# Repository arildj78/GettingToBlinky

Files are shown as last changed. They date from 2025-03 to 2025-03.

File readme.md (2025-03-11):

# Getting to Blinky
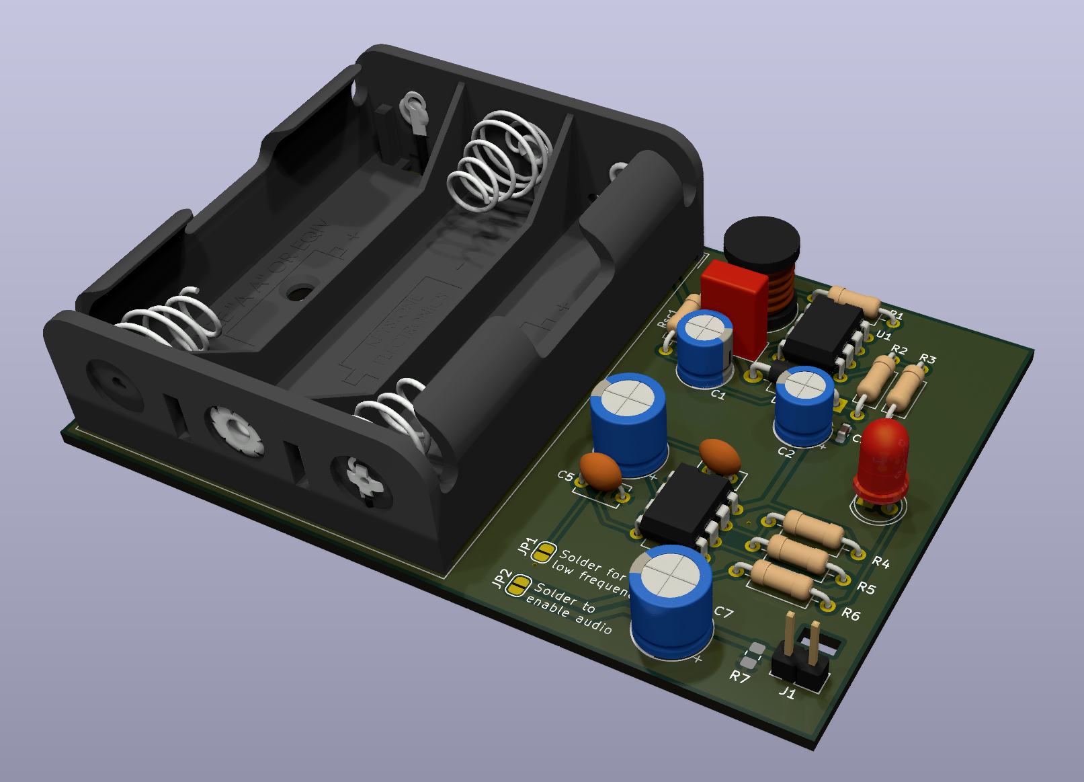
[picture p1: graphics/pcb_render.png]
Rendering of the pcb

This project is designed to introduce you to KiCad and electronics design. The gadget is battery powered and will blink a high luminosity LED as well as output a tone to a speaker. The frequency can be switched between 1 Hz and 440Hz with a solder jumper. The two integrated circuits are classics and are considered [jellybean](https://forum.digikey.com/t/what-are-jellybean-electronic-components/46180) parts.

## The schematic
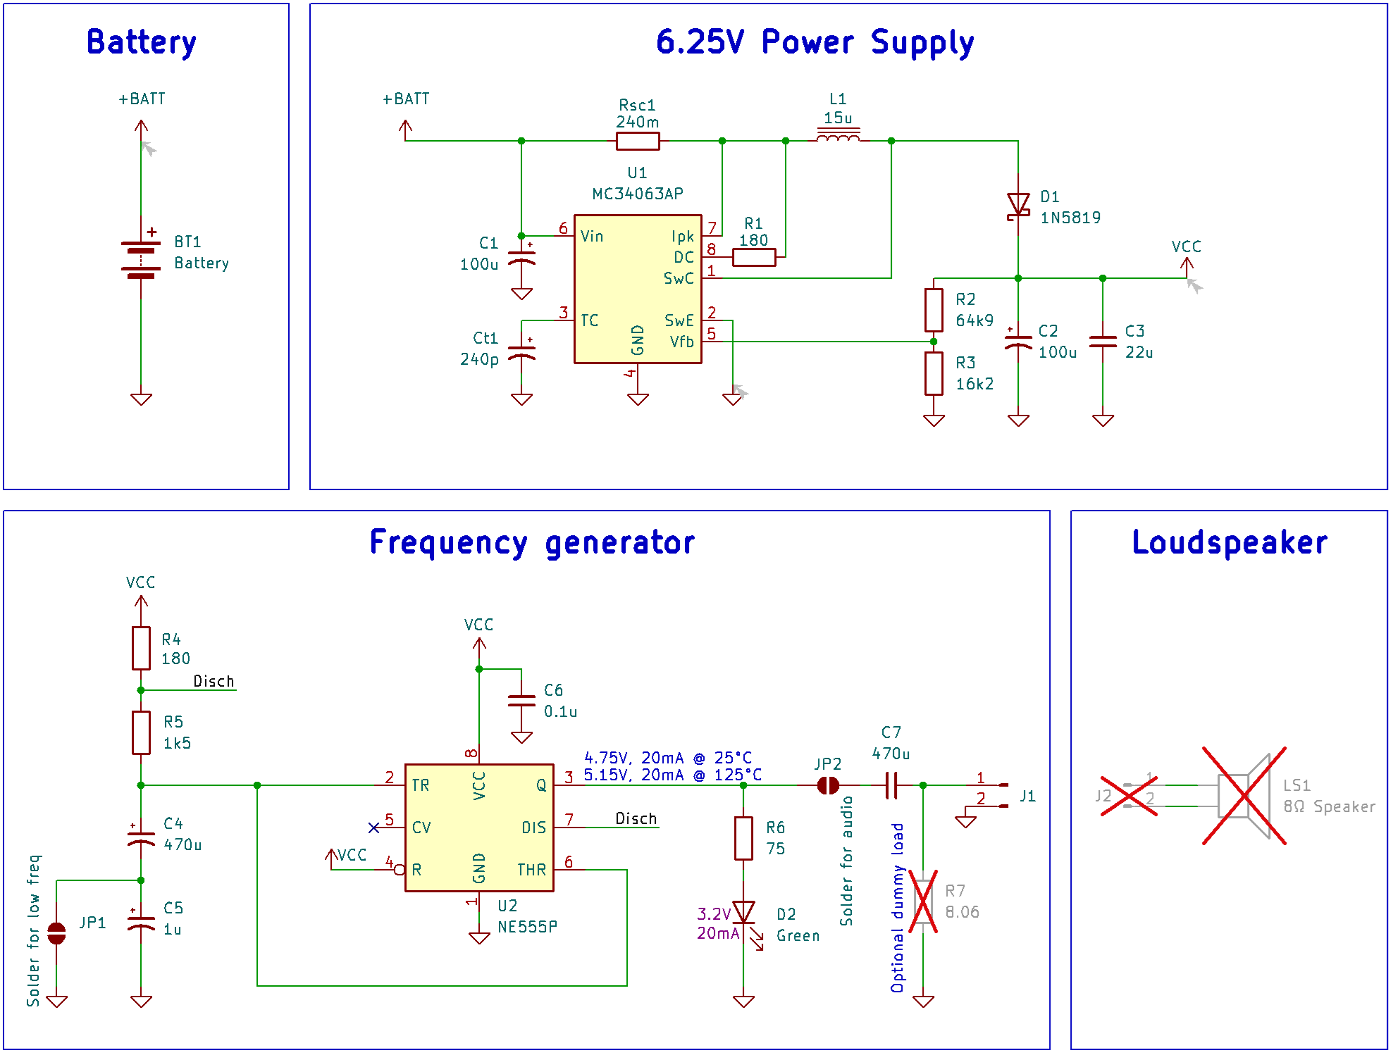
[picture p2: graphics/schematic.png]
Image of the schematic


## General design requirements
* Power supplied by [3 x AA batteries](https://www.digikey.no/en/products/detail/keystone-electronics/2464/303813)
* Generate the pulsed signal with a [555 timer](/datasheets/ne555.pdf) chip
* Boost the battery voltage with the [MC34063](/datasheets/MC34063A-D.pdf) DC-DC regulator
* Let the 555 timer drive 0.25 Watt into an 8Ω speaker without an additional amplifier
* Use only through hole parts in the design with two small exceptions
* Familiarize the designer with SMD parts of imperial size 0603 and 0805.
* Introduce some of the tools and techniques that are useful in KiCad
* Cut a slot in the PCB to use as strain relief for the speaker cable
* Use a two layer pcb design

## DC-DC regulator design decisions
* Input voltage 3.75V ±20%
    * An assumption is made that an alkaline cell with 50% of the energy left is at approximately 1.25V. We are using three of these in series.
* Output current 150mA
    * This is a compromise. Not all the way to 0.25 watt on the speaker and not maxing out the available current from the 555 timer chip. May change after prototyping.
* Output Voltage 6.25V
    * The voltage needs to be this high to get 2.4V voltage swing on the output when pulling 150mA from the output of the 555.
* Switching frequency 100kHz
    * A high switching frequency lets the inductor be small. This is the maximum frequency supported by the selected regulator.
* Output ripple voltage 100mV
    * An arbitrary value. Same as Dave chose in the YouTube video [EEVblog #110 - Let's Design a DC to DC Switch mode Converter](https://youtu.be/qGp82xhybs4).

## Teaching points in Schematic Editor
* Getting started with a new project i KiCad
* Placing parts and connecting them on the schematic
    * Place
    * Rotate
    * Mirror
    * Move
    * Grab
    * Wire
* Implementing the typical application found in the MC34063 and 555 datasheets
* Choosing component values from [E series of preferred numbers](https://en.wikipedia.org/wiki/E_series_of_preferred_numbers)
* Searching for parts on [DigiKey](https://digikey.com), [JLCPCB](https://jlcpcb.com/parts) and [LCSC](https://www.lcsc.com/)
* Choosing footprints
* Adding symbol data by using *fields* and the *Symbol Fields Table*
* Using the *Do not populate* and *Exclude from Bill Of Materials* (BOM) option
* The purpose of the 0.1µF decoupling capacitor
* Dividing a schematic into functional blocks
* Annotating the schematic
* Running Electrical Rules Check

## Teaching points in PCB Editor
* Switching from schematic to pcb
* Update PCB from schematic
* Move components into functional blocks
* Untangle the ratsnest
* Draw board outline
* Pre-define sizes for tracks and vias.
    * 0.3mm (0.012") track
    * 0.7mm (0.028") track
    * 1.0mm / 0.4mm via
* Route Tracks
    * Track size
    * Use of vias and multiple layers
* Create filled zones for ground (and power if the board had more layers)
* Use the 3D-viewer
* Use the Design Rules Check

## Suggested Parts list
|Reference |Value |Manufacturer |Part# |DigiKey# |Qty|
|---|---|---|---|---|---|
|BT1 |Battery  |Keystone Electronics |2464 |36-2464-ND |  1|
|C1,C2 |100u |Chinsan (Elite) |ED1E101MP26311U |4191-ED1E101MP26311UCT-ND  |  2|
|C3 |22u |Murata Electronics |GRM188C61E226ME01J|490-GRM188C61E226ME01JCT-ND|  1|
|C4,C7 |470u |Chinsan (Elite) |EK1C471MP30812 |4191-EK1C471MP30812CT-ND |  2|
|C5 |1u |TDK Corporation |FG24X7R1H105KRT06 |445-173374-1-ND |  1|
|C6 |0.1u |KEMET |C320C104M5R5TA |399-9776-ND |  1|
|Ct1 |240p |KEMET |C318C241K3G5TA |C318C241K3G5TA-ND |  1|
|D1 |1N5819 |STMicroelectronics |1N5819 |497-6610-1-ND |  1|
|D2 |Green |Inolux |INL-5AG30 |1830-1011-ND |  1|
|L1 |15u |Bourns Inc. |RLB0913-150K |RLB0913-150K-ND |  1|
|R1,R4 |180 |Stackpole Electronics Inc  |CF14JT180R |CF14JT180RCT-ND |  2|
|R2 |64k9 |YAGEO |MFR-25FRF52-64K9  |13-MFR-25FRF52-64K9CT-ND |  1|
|R3 |16k2 |YAGEO |MFR-25FTE52-16K2  |13-MFR-25FTE52-16K2CT-ND |  1|
|R5 |1k5 |YAGEO |MFR-25FTF52-1K5 |13-MFR-25FTF52-1K5CT-ND |  1|
|R6 |75 |Stackpole Electronics Inc  |CF14JT75R0 |CF14JT75R0CT-ND |  1|
|R7 |8.06 |KOA Speer Electronics, Inc.|RK73H2ATTD8R06F |2019-RK73H2ATTD8R06FCT-ND  |  1|
|Rsc1 |240m |YAGEO |MFR-25JR-52-0R24  |13-MFR-25JR-52-0R24CT-ND |  1|
|U1 |MC34063AP|onsemi |MC34063AP1G |MC34063AP1GOS-ND |  1|
|U2 |NE555P |Texas Instruments |NE555P |296-NE555P-ND |  1|

## Suggested Footprints
|Reference |Footprint |
|---|---|
|BT1 |Battery:BatteryHolder_TruPower_BH-331P_3xAA |
|C1,C2 |Capacitor_THT:CP_Radial_D6.3mm_P2.50mm |
|C3 |Capacitor_SMD:C_0603_1608Metric_Pad1.08x0.95mm_HandSolder |
|C4,C7 |Capacitor_THT:CP_Radial_D8.0mm_P3.50mm |
|C5 |Capacitor_THT:C_Disc_D5.1mm_W3.2mm_P5.00mm |
|C6 |Capacitor_THT:C_Disc_D5.0mm_W2.5mm_P2.50mm |
|Ct1 |Capacitor_THT:C_Rect_L7.0mm_W3.5mm_P5.00mm |
|D1 |Diode_THT:D_DO-41_SOD81_P10.16mm_Horizontal |
|D2 |LED_THT:LED_D5.0mm |
|L1 |Inductor_THT:L_Radial_D8.7mm_P5.00mm_Fastron_07HCP |
|R1,R2,R3,R4,R5,R6,Rsc1|Resistor_THT:R_Axial_DIN0207_L6.3mm_D2.5mm_P10.16mm_Horizontal|
|R7 |Resistor_SMD:R_0805_2012Metric_Pad1.20x1.40mm_HandSolder |
|U1,U2 |Package_DIP:DIP-8_W7.62mm |

## Reference material
* [EEVblog #110 - Let's Design a DC to DC Switch mode Converter](https://youtu.be/qGp82xhybs4)

## Useful tools
* [KiCad](https://www.kicad.org/)
* [LTspice circuit simulator](https://www.analog.com/en/resources/design-tools-and-calculators/ltspice-simulator.html)
* [Saturn PCB Design Toolkit](https://saturnpcb.com/saturn-pcb-toolkit/)
* [Resistor calculator](https://damien.douxchamps.net/elec/resdiv/)

## Useful web services
* [jlcpcb.com](https://jlcpcb.com/)
* [digikey.com](https://www.digikey.com)
* [lcsc.com](https://www.lcsc.com/)
* [Falstad circuit simulator](https://www.falstad.com/circuit/circuitjs.html)

## My favorite podcasts
* [The Amp Hour](https://theamphour.com/)
* [Embedded FM](https://embedded.fm/)
* [Hackaday](https://hackaday.com/tag/hackaday-podcast/)
* [The Unnamed Reverse Engineering Podcast](https://unnamedre.com/)

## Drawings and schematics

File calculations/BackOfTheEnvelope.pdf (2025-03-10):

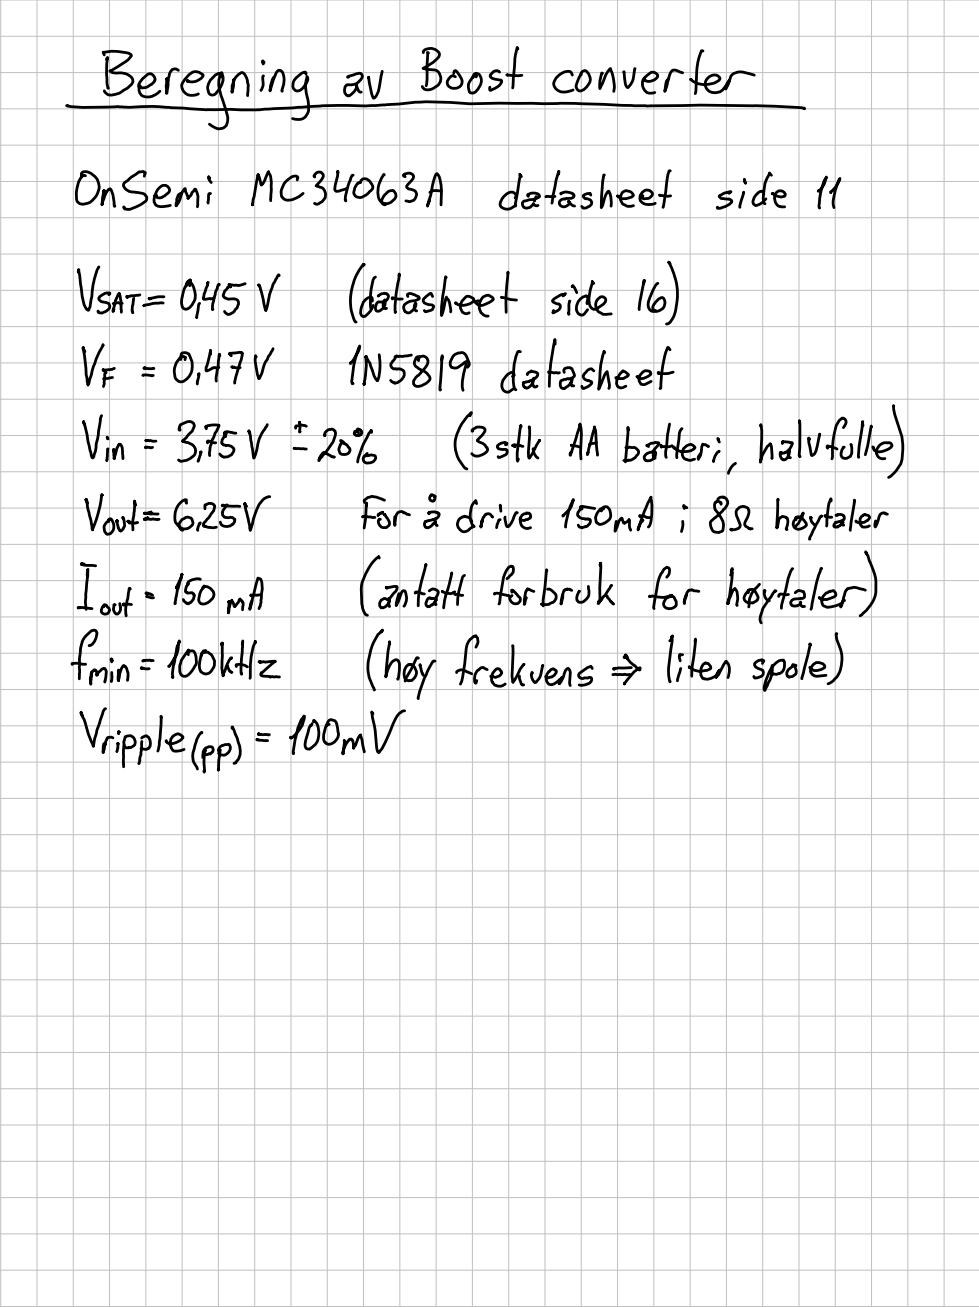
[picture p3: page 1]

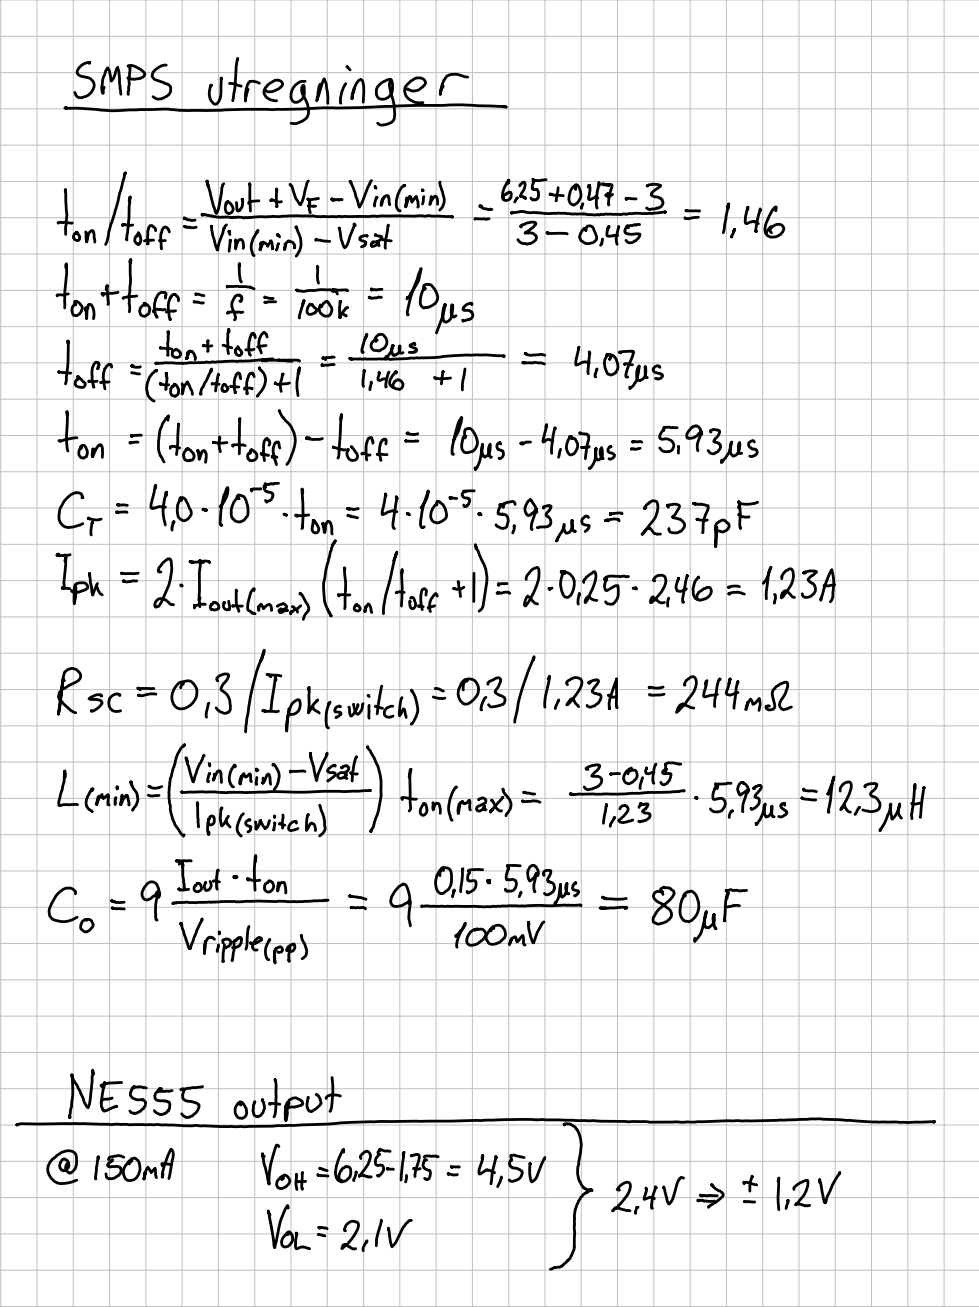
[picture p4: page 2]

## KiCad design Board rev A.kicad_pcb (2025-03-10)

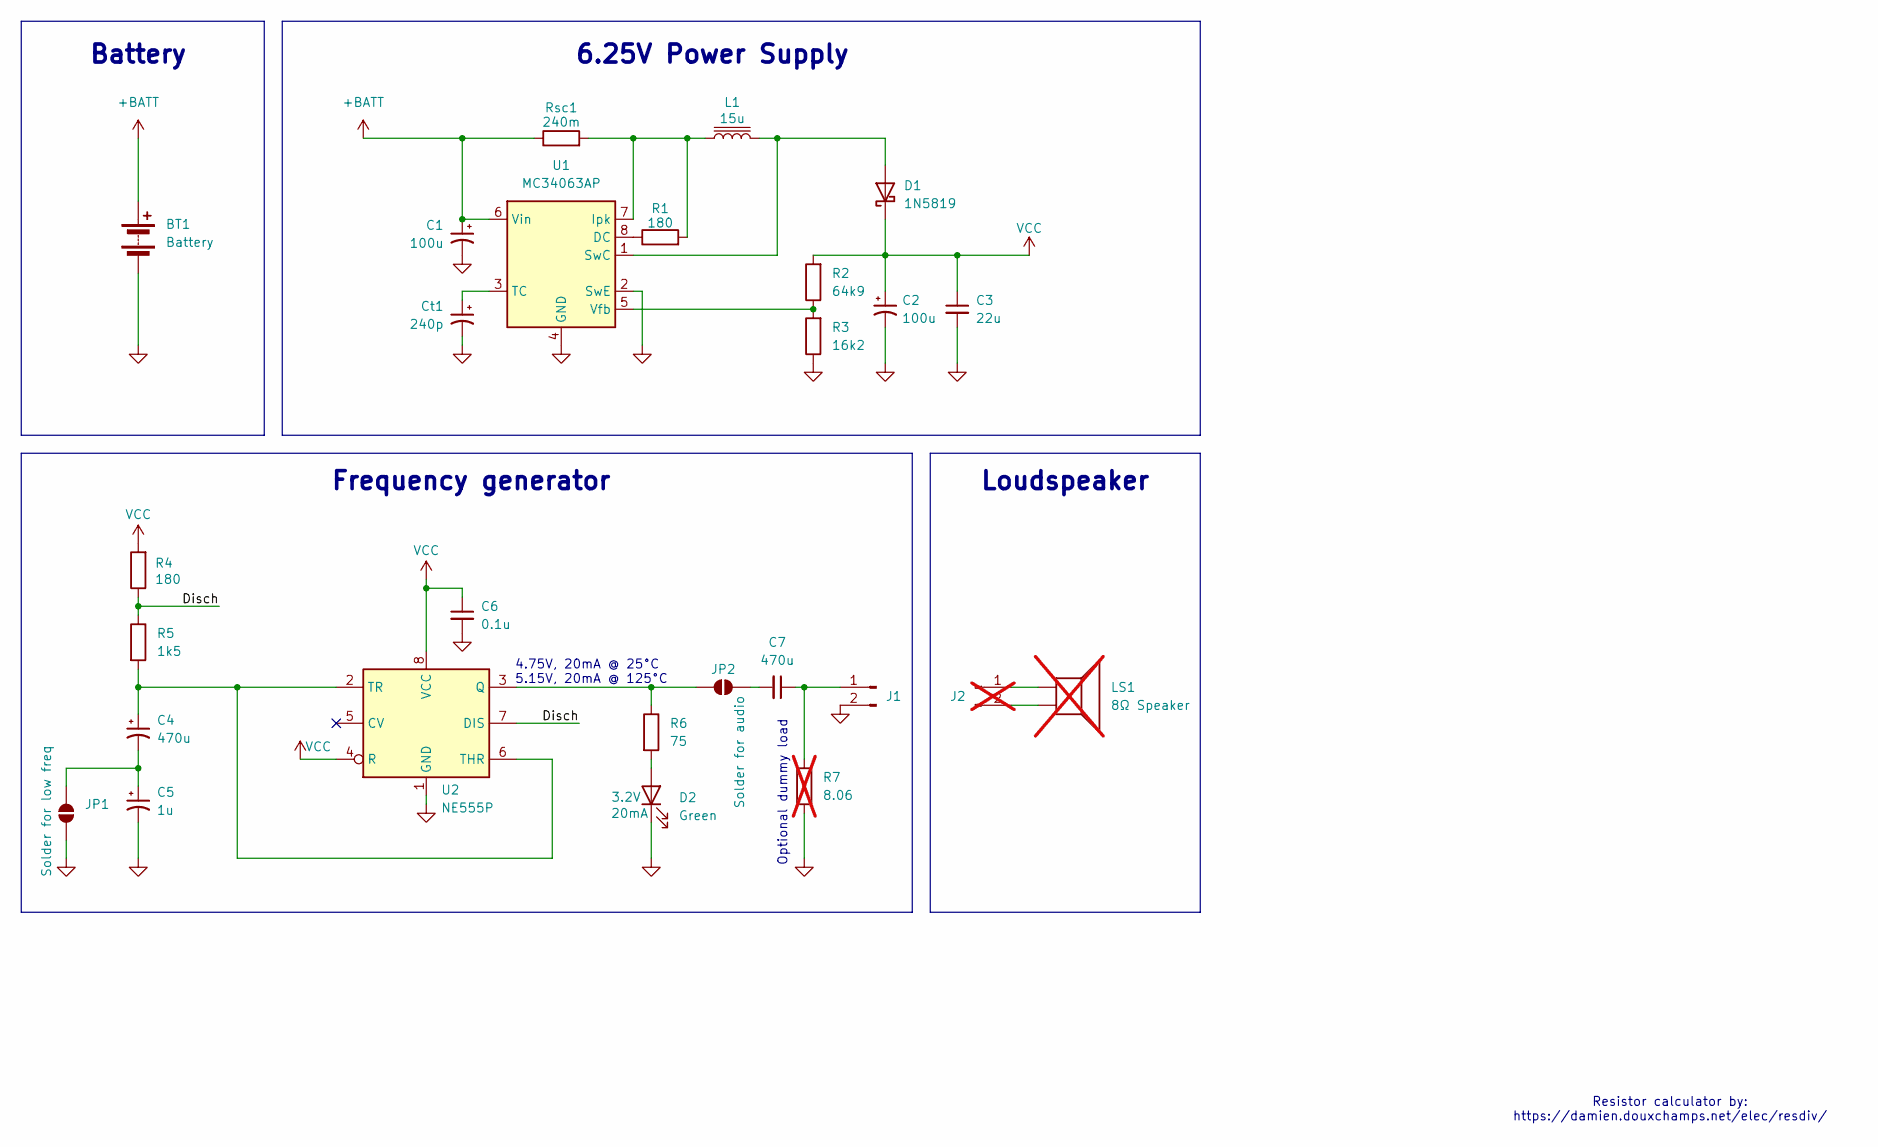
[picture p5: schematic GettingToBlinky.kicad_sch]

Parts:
BT1: Battery; BatteryHolder_TruPower_BH-331P_3xAA; Part# 2464; DigiKey# 36-2464-ND
C1, C2: 100u; CP_Radial_D6.3mm_P2.50mm; Part# ED1E101MP26311U; DigiKey# 4191-ED1E101MP26311UCT-ND
C3: 22u; C_0603_1608Metric_Pad1.08x0.95mm_HandSolder; Part# GRM188C61E226ME01J; DigiKey# 490-GRM188C61E226ME01JCT-ND
C4, C7: 470u; CP_Radial_D8.0mm_P3.50mm; Part# EK1C471MP30812; DigiKey# 4191-EK1C471MP30812CT-ND
C5: 1u; C_Disc_D5.1mm_W3.2mm_P5.00mm; Part# FG24X7R1H105KRT06; DigiKey# 445-173374-1-ND
C6: 0.1u; C_Disc_D5.0mm_W2.5mm_P2.50mm; Part# C320C104M5R5TA; DigiKey# 399-9776-ND
Ct1: 240p; C_Rect_L7.0mm_W3.5mm_P5.00mm; Part# C318C241K3G5TA; DigiKey# C318C241K3G5TA-ND
D1: 1N5819; D_DO-41_SOD81_P10.16mm_Horizontal; Part# 1N5819; DigiKey# 497-6610-1-ND
D2: Green; LED_D5.0mm; Part# INL-5AG30; DigiKey# 1830-1011-ND
J1: Conn_01x02_Pin; PinHeader_1x02_P2.54mm_Vertical
J2: Conn_01x02_Pin; PinHeader_1x02_P2.54mm_Vertical; not fitted
JP1: Solder for low freq; SolderJumper-2_P1.3mm_Open_RoundedPad1.0x1.5mm
JP2: Solder for audio; SolderJumper-2_P1.3mm_Open_RoundedPad1.0x1.5mm
L1: 15u; L_Radial_D8.7mm_P5.00mm_Fastron_07HCP; Part# RLB0913-150K; DigiKey# RLB0913-150K-ND
LS1: 8Ω Speaker; not fitted
R1, R4: 180; R_Axial_DIN0207_L6.3mm_D2.5mm_P10.16mm_Horizontal; Part# CF14JT180R; DigiKey# CF14JT180RCT-ND
R2: 64k9; R_Axial_DIN0207_L6.3mm_D2.5mm_P10.16mm_Horizontal; Part# MFR-25FRF52-64K9; DigiKey# 13-MFR-25FRF52-64K9CT-ND
R3: 16k2; R_Axial_DIN0207_L6.3mm_D2.5mm_P10.16mm_Horizontal; Part# MFR-25FTE52-16K2; DigiKey# 13-MFR-25FTE52-16K2CT-ND
R5: 1k5; R_Axial_DIN0207_L6.3mm_D2.5mm_P10.16mm_Horizontal; Part# MFR-25FTF52-1K5; DigiKey# 13-MFR-25FTF52-1K5CT-ND
R6: 75; R_Axial_DIN0207_L6.3mm_D2.5mm_P10.16mm_Horizontal; Part# CF14JT75R0; DigiKey# CF14JT75R0CT-ND
R7: 8.06; R_0805_2012Metric_Pad1.20x1.40mm_HandSolder; Part# RK73H2ATTD8R06F; DigiKey# 2019-RK73H2ATTD8R06FCT-ND; not fitted
Rsc1: 240m; R_Axial_DIN0207_L6.3mm_D2.5mm_P10.16mm_Horizontal; Part# MFR-25JR-52-0R24; DigiKey# 13-MFR-25JR-52-0R24CT-ND
U1: MC34063AP; DIP-8_W7.62mm; Part# MC34063AP1G; DigiKey# MC34063AP1GOS-ND
U2: NE555P; DIP-8_W7.62mm; Part# NE555P; DigiKey# 296-NE555P-ND

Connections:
+BATT: BT1.1 (+), C1.1, Rsc1.1, U1.6 (Vin)
/Disch: R4.1, R5.1, U2.7 (DIS)
GND: BT1.2 (-), C1.2, C2.2, C3.2, C5.2, C6.2, Ct1.2, D2.1 (K), J1.2, JP1.1 (A), R3.1, R7.2, U1.2 (SwE), U1.4 (GND), U2.1 (GND)
unnamed: D1.2 (A), L1.2, U1.1 (SwC)
unnamed: D2.2 (A), R6.2
unnamed: C7.1, J1.1, R7.1
unnamed: J2.1, LS1.1
unnamed: J2.2, LS1.2
unnamed: C4.2, C5.1, JP1.2 (B)
unnamed: C7.2, JP2.1 (A)
unnamed: JP2.2 (B), R6.1, U2.3 (Q)
unnamed: R1.1, U1.8 (DC)
unnamed: L1.1, R1.2, Rsc1.2, U1.7 (Ipk)
unnamed: Ct1.1, U1.3 (TC)
unnamed: R2.1, R3.2, U1.5 (Vfb)
unnamed: C4.1, R5.2, U2.2 (TR), U2.6 (THR)
VCC: C2.1, C3.1, C6.1, D1.1 (K), R2.2, R4.2, U2.4 (R), U2.8 (VCC)

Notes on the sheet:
4.75V, 20mA @ 25°C 5.15V, 20mA @ 125°C
Resistor calculator by: https://damien.douxchamps.net/elec/resdiv/
6.25V Power Supply
Optional dummy load
Loudspeaker
Battery
Frequency generator

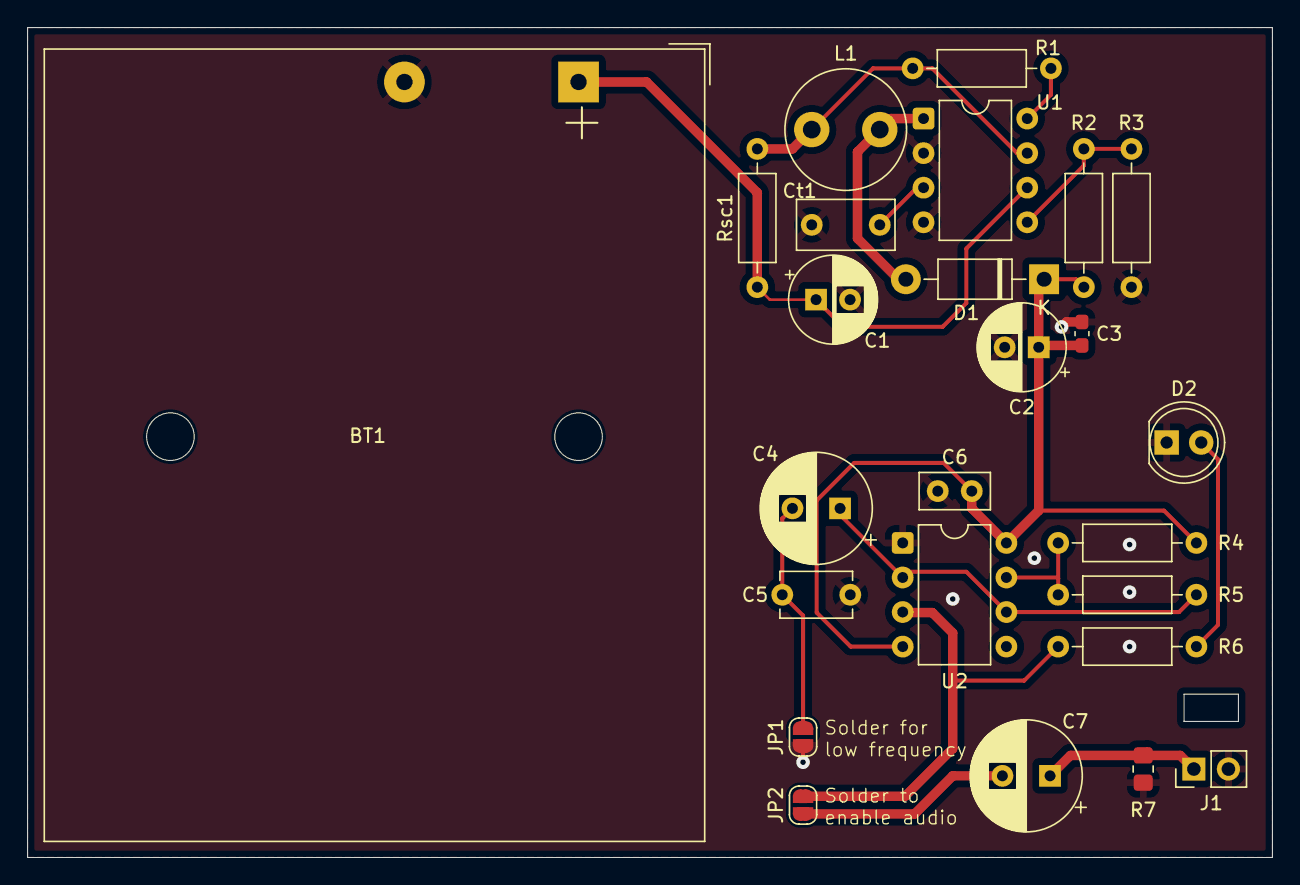
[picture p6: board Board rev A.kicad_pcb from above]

Board: 2 copper layers, 91.5 x 61.0 mm, 25 parts (0 on the bottom side), 15 nets.

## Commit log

2025-03-11 Moved individual gerber files into separate folder
    [GettingToBlinky-B_Cu.gbr, GettingToBlinky-B_Mask.gbr, GettingToBlinky-B_Silkscreen.gbr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]
2025-03-11 Renamed the board file to Rev A. This lets the user start with a blank sheet when entering the PCB editor.
    [Board rev A.kicad_pcb]
2025-03-11 Added design decisions and image of the schematic
